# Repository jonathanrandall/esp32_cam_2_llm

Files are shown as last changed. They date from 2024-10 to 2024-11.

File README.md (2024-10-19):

# esp32_cam_2_llm
connect an esp32 cam to llm and back again

The project connects an esp32 cam to an LLM, which takes as input the prompt "describe this picture?" together with the image, and then returns a description of the image. The returned description is then transformed into speech. The LLM is running locally on my machine. I'm using the [ollama library](https://ollama.com/) with LLAVA model. The __LLAVA open source model__ is good for doing image analysis. I'm using an MSI laptop with an NVIDIA 4070 GPU, which has 8GB of vram. The llava model can be installed directoy with ollama. 

Thanks to pcbway for the pcbs. https://www.pcbway.com

### explanatory video:

https://youtu.be/hMA0HNYTjm0

### repository files:

* __llm_2_esp32_cam.py__: this file is running on my local maching.
* __esp32_2_llm__: this contains the test internet radio file from the audio [esp32-i2s library](https://github.com/schreibfaul1/ESP32-audioI2S). Try to get this working first to troubleshoot any i2s difficulties.
* __esp32_2_llmv4__: this contains the code running on the eps32 cam that communicates with the llm.
* __fritzing__: fritzing file and gerbers for pcb.

### connections I used
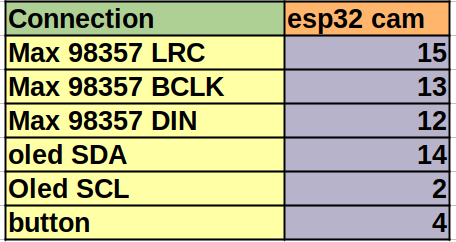
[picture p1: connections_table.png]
connection list


### equipment list

* __esp32 cam__: I'm using the AI thinker.
* __MAX 98357__: Audio amplifier.
* __speakers__: 8 ohm or 4 ohm speakers. It's worth getting good ones. Cheaper ones are at aliexpress (https://www.aliexpress.com/item/1005006056014552.html). More expensive ones are at Amazon (https://www.amazon.com.au/dp/B01LN8ONG4).
* __FTDI adapter__: Need this to flash the esp32 cam if you're using the AI thinker.
* __pcb or breadboard__: I used both. I built on the breadboard first and then put everything on a pcb.
* __oled__: I used a 128 x 64 oled.
* __18650 battery__
* __18650 WEMOS battery shield__: see https://www.amazon.com.au/Be-Your-Mind-Expansion-Compatible/dp/B0CPDD985S for example.
* __push button__
* __rocker switch__
* __jumper cables__

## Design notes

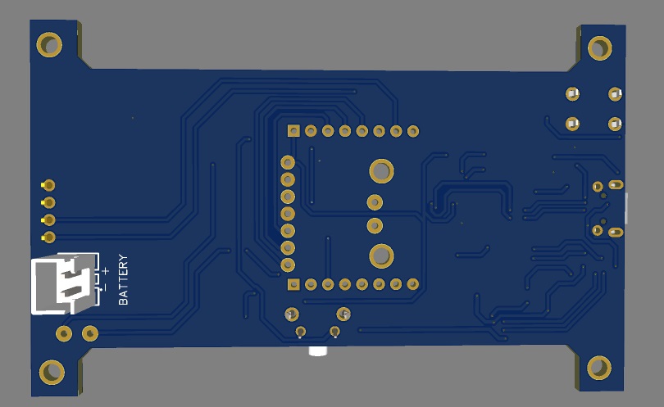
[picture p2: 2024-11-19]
fritzing/llmB.jpg

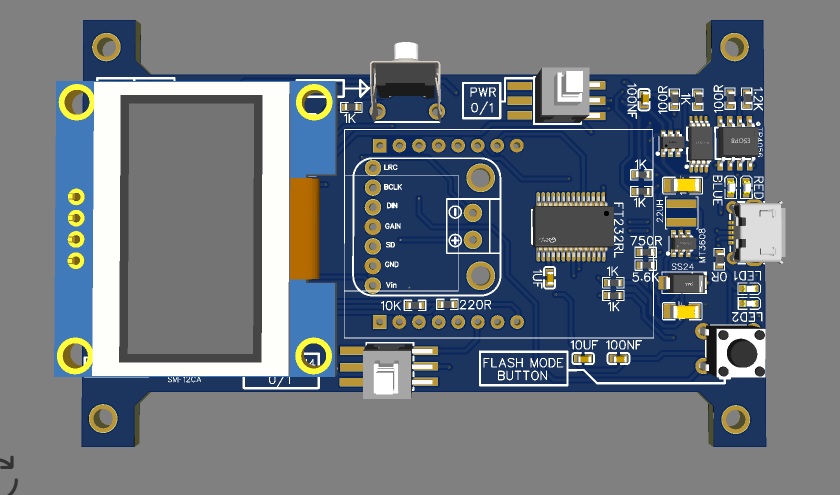
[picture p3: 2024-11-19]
fritzing/llmA.jpg

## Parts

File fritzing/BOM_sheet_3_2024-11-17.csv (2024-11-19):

ID | Name | Designator | Footprint | Quantity | Manufacturer Part | Manufacturer | Supplier | Supplier Part | Price | JLCPCB Part Class | Value
1 | CONN-TH_2P-P2.50_HX254 | U153 | CONN-TH_2P-P2.50_HX254 | 1 | HX2.54_2 | null | LCSC | C9900001962 |  | Extended Part
2 | SOD-123_L2.8-W1.8-LS3.7-BI | D1 | SOD-123_L2.8-W1.8-LS3.7-BI | 1 | SMF12CA | SUNMATE(森美特) | LCSC | C399256 | 0.029 | Extended Part
3 | ESP32-CAM | 1 | ESP32-CAM | 1
4 | SW-SMD_G-SWITCH_PS-5850SVX-3PL | U148,U8 | SW-SMD_G-SWITCH_PS-5850SVX-3PL | 2 | PS-5850SVB-3PL | G-Switch(品赞) | LCSC | C5159077 | 0.152 | Extended Part
5 | R0603 | 1K,1K,1K,1K,1K,1K | R0603 | 6 | RC0603JR-071KL | YAGEO(国巨) | LCSC | C14676 | 0.001 | Extended Part | 1kΩ
6 | KEY-TH_E-SWITCH_TL6110BF500QP | U7 | KEY-TH_E-SWITCH_TL6110BF500QP | 1 | TL6110BF500QP | E-Switch | LCSC | C4364940 | 0.706
7 | R0603 | 100R,100R | R0603 | 2 | AC0603FR-7W100RL | YAGEO(国巨) | LCSC | C6457824 | 0.004 | Extended Part | 100Ω
8 | C0603 | 100NF,100NF | C0603 | 2 | 0603B104K250CT | Walsin(华新科) | LCSC | C83054 | 0.003 | Extended Part | 100nF
9 | LED0603-RD | BLUE,RED,LED1,LED2 | LED0603-RD | 4 | YLED0603B | YONGYUTAI(永裕泰) | LCSC | C19171394 | 0.005 | Extended Part
10 | SSOP-28_L10.2-W5.3-P0.65-LS7.8-BL | U2 | SSOP-28_L10.2-W5.3-P0.65-LS7.8-BL | 1 | FT232RL-REEL | FTDI(飞特帝亚) | LCSC | C8690 | 4.152 | Extended Part
11 | C0603 | 1UF | C0603 | 1 | CC0603KRX5R8BB105 | YAGEO(国巨) | LCSC | C14664 | 0.005 | Extended Part | 1uF
12 | C0603 | 10UF | C0603 | 1 | HGC0603R5106M250NTHJ | Chinocera(华瓷) | LCSC | C7472961 | 0.015 | Extended Part | 10uF
13 | R0603 | 0R | R0603 | 1 | CR-03FL7----0R | Viking(光颉) | LCSC | C304185 | 0.002 | Extended Part | 0Ω
14 | R0603 | 1.2K | R0603 | 1 | RMC06031.2K1%N | Tyohm(幸亚电阻) | LCSC | C325597 | 0.003 | Extended Part | 1.2kΩ
15 | R0603 | 750R | R0603 | 1 | AECR0603F750RK9 | RESI(开步睿思) | LCSC | C328375 | 0.001 | Extended Part | 750Ω
16 | R0603 | 5.6K | R0603 | 1 | RMC06035.6K5%N | Tyohm(幸亚电阻) | LCSC | C325756 | 0.002 | Extended Part | 5.6kΩ
17 | R0603 | 10K | R0603 | 1 | AC0603FR-0710KL | YAGEO(国巨) | LCSC | C116677 | 0.002 | Extended Part | 10kΩ
18 | R0603 | 220R | R0603 | 1 | RC0603JR-07220RL | YAGEO(国巨) | LCSC | C114683 | 0.001 | Extended Part | 220Ω
19 | KEY-TH_4P-L6.0-W6.0-P4.50 | U3 | KEY-TH_4P-L6.0-W6.0-P4.50 | 1 | button6*6*8.5 | ReliaPro | LCSC | C59980 | 0.016 | Extended Part
20 | IND-SMD_L4.0-W4.0-A | L4 | IND-SMD_L4.0-W4.0-A | 1 | XFL4020-102ME | null | LCSC | C9900014800 |  | Extended Part
21 | C1206 | C87,C86 | C1206 | 2 | GRM31CR60J476ME19L | muRata(村田) | LCSC | C77087 | 0.083 | Extended Part | 47uF
22 | SOT-23-6_L2.9-W1.6-P0.95-LS2.8-BL | U147 | SOT-23-6_L2.9-W1.6-P0.95-LS2.8-BL | 1 | MT3608 | 西安航天民芯 | LCSC | C84817 | 0.062 | Extended Part
23 | SMA_L4.4-W2.6-LS5.0-RD | D20 | SMA_L4.4-W2.6-LS5.0-RD | 1 | SM340A | LRC(乐山无线电) | LCSC | C383313 | 0.032 | Extended Part
24 | 0.96OLED_4P | OLED1 | 0.96OLED_4P | 1 | 0.96OLED_4P_MODULE_JX | null | LCSC | C9900004566 |  | Extended Part
25 | MAX98357A | U6 | MAX98357A | 1 |  |  | ebay
26 | ESOP-8_L4.9-W3.9-P1.27-LS6.0-BL-EP | U103 | ESOP-8_L4.9-W3.9-P1.27-LS6.0-BL-EP | 1 | TP4056 | null | LCSC | C9900002169 |  | Extended Part
27 | TSSOP-8_L4.4-W3.0-P0.65-LS6.4-BL | U102 | TSSOP-8_L4.4-W3.0-P0.65-LS6.4-BL | 1 | 8205LA | FM(富满) | LCSC | C7420387 | 0.031
28 | SOT-23-6_L2.9-W1.6-P0.95-LS2.9-BL | U101 | SOT-23-6_L2.9-W1.6-P0.95-LS2.9-BL | 1 | DW01-G | FORTUNE(富晶) | LCSC | C3020704
29 | MICRO-USB_MICRO-USB-30 | USB2 | MICRO-USB_MICRO-USB-30 | 1 | 920-E52A2021S10101 | 精拓金 | LCSC | C40946 | 0.069 | Extended Part

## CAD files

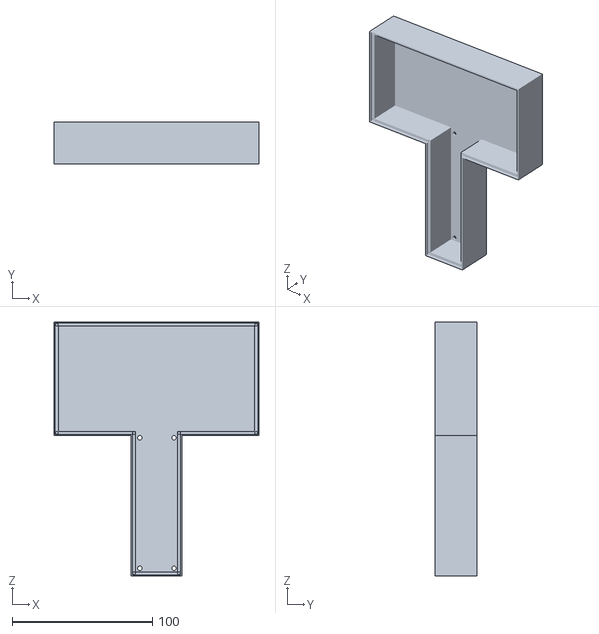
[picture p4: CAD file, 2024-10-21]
3d_prints/box-Body.stl
146.0 x 30.0 x 181.0

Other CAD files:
3d_prints/project_box_esp32_llm.FCStd

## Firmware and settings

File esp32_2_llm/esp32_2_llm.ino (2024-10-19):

/*
  Simple Internet Radio Demo
  esp32-i2s-simple-radio.ino
  Simple ESP32 I2S radio
  Uses MAX98357 I2S Amplifier Module
  Uses ESP32-audioI2S Library - https://github.com/schreibfaul1/ESP32-audioI2S

  DroneBot Workshop 2022
  https://dronebotworkshop.com
*/

// Include required libraries
#include "Arduino.h"
#include "WiFi.h"
#include "Audio.h"

#define RTC_CNTL_BROWN_OUT_REG          (DR_REG_RTCCNTL_BASE + 0xd4)

// Define I2S connections
#define I2S_DOUT  12
#define I2S_BCLK  13
#define I2S_LRC   15

// Create audio object
Audio audio;

// Wifi Credentials
String ssid =    "";
String password = "";

void setup() {
  WRITE_PERI_REG(RTC_CNTL_BROWN_OUT_REG, 0); //disable brownout detector

  // Start Serial Monitor
  Serial.begin(115200);

  // Setup WiFi in Station mode
  WiFi.disconnect();
  WiFi.mode(WIFI_STA);
  WiFi.begin(ssid.c_str(), password.c_str());

  while (WiFi.status() != WL_CONNECTED) {
    delay(500);
    Serial.print(".");
  }

  // WiFi Connected, print IP to serial monitor
  Serial.println("");
  Serial.println("WiFi connected");
  Serial.println("IP address: ");
  Serial.println(WiFi.localIP());
  Serial.println("");

  // Connect MAX98357 I2S Amplifier Module
  audio.setPinout(I2S_BCLK, I2S_LRC, I2S_DOUT);

  // Set thevolume (0-100)
  audio.setVolume(10);

  // Connect to an Internet radio station (select one as desired)
  audio.connecttohost("http://vis.media-ice.musicradio.com/CapitalMP3");
  //audio.connecttohost("mediaserv30.live-nect MAX98357 I2S Amplifier Module
  //audio.connecttohost("www.surfmusic.de/m3u/100-5-das-hitradio,4529.m3u");
  //audio.connecttohost("stream.1a-webradio.de/deutsch/mp3-128/vtuner-1a");
  //audio.connecttohost("www.antenne.de/webradio/antenne.m3u");
  // audio.connecttohost("0n-80s.radionetz.de:8000/0n-70s.mp3");

}

void loop()

{
  // Run audio player
  audio.loop();

}

// Audio status functions

void audio_info(const char *info) {
  Serial.print("info        "); Serial.println(info);
}
void audio_id3data(const char *info) { //id3 metadata
  Serial.print("id3data     "); Serial.println(info);
}
void audio_eof_mp3(const char *info) { //end of file
  Serial.print("eof_mp3     "); Serial.println(info);
}
void audio_showstation(const char *info) {
  Serial.print("station     "); Serial.println(info);
}
void audio_showstreaminfo(const char *info) {
  Serial.print("streaminfo  "); Serial.println(info);
}
void audio_showstreamtitle(const char *info) {
  Serial.print("streamtitle "); Serial.println(info);
}
void audio_bitrate(const char *info) {
  Serial.print("bitrate     "); Serial.println(info);
}
void audio_commercial(const char *info) { //duration in sec
  Serial.print("commercial  "); Serial.println(info);
}
void audio_icyurl(const char *info) { //homepage
  Serial.print("icyurl      "); Serial.println(info);
}
void audio_lasthost(const char *info) { //stream URL played
  Serial.print("lasthost    "); Serial.println(info);
}
void audio_eof_speech(const char *info) {
  Serial.print("eof_speech  "); Serial.println(info);
}

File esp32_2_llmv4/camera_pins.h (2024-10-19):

#ifndef PINS_STUFF_
#define PINS_STUFF_

// Select camera model
// #define CAMERA_MODEL_WROVER_KIT // Has PSRAM
//#define CAMERA_MODEL_ESP_EYE // Has PSRAM
//#define CAMERA_MODEL_M5STACK_PSRAM // Has PSRAM
//#define CAMERA_MODEL_M5STACK_WIDE  // Has PSRAM
#define CAMERA_MODEL_AI_THINKER // Has PSRAM
//#define CAMERA_MODEL_TTGO_T_JOURNAL // No PSRAM
// #define CAMERA_MODEL_XIAO_ESP32S3 // Has PSRAM
#if defined(CAMERA_MODEL_WROVER_KIT)
#define PWDN_GPIO_NUM    -1
#define RESET_GPIO_NUM   -1
#define XCLK_GPIO_NUM    21
#define SIOD_GPIO_NUM    26
#define SIOC_GPIO_NUM    27

#define Y9_GPIO_NUM      35
#define Y8_GPIO_NUM      34
#define Y7_GPIO_NUM      39
#define Y6_GPIO_NUM      36
#define Y5_GPIO_NUM      19
#define Y4_GPIO_NUM      18
#define Y3_GPIO_NUM       5
#define Y2_GPIO_NUM       4
#define VSYNC_GPIO_NUM   25
#define HREF_GPIO_NUM    23
#define PCLK_GPIO_NUM    22

#elif defined(CAMERA_MODEL_ESP_EYE)
#define PWDN_GPIO_NUM    -1
#define RESET_GPIO_NUM   -1
#define XCLK_GPIO_NUM    4
#define SIOD_GPIO_NUM    18
#define SIOC_GPIO_NUM    23

#define Y9_GPIO_NUM      36
#define Y8_GPIO_NUM      37
#define Y7_GPIO_NUM      38
#define Y6_GPIO_NUM      39
#define Y5_GPIO_NUM      35
#define Y4_GPIO_NUM      14
#define Y3_GPIO_NUM      13
#define Y2_GPIO_NUM      34
#define VSYNC_GPIO_NUM   5
#define HREF_GPIO_NUM    27
#define PCLK_GPIO_NUM    25

#define LED_GPIO_NUM     22

#elif defined(CAMERA_MODEL_M5STACK_PSRAM)
#define PWDN_GPIO_NUM     -1
#define RESET_GPIO_NUM    15
#define XCLK_GPIO_NUM     27
#define SIOD_GPIO_NUM     25
#define SIOC_GPIO_NUM     23

#define Y9_GPIO_NUM       19
#define Y8_GPIO_NUM       36
#define Y7_GPIO_NUM       18
#define Y6_GPIO_NUM       39
#define Y5_GPIO_NUM        5
#define Y4_GPIO_NUM       34
#define Y3_GPIO_NUM       35
#define Y2_GPIO_NUM       32
#define VSYNC_GPIO_NUM    22
#define HREF_GPIO_NUM     26
#define PCLK_GPIO_NUM     21

#elif defined(CAMERA_MODEL_M5STACK_V2_PSRAM)
#define PWDN_GPIO_NUM     -1
#define RESET_GPIO_NUM    15
#define XCLK_GPIO_NUM     27
#define SIOD_GPIO_NUM     22
#define SIOC_GPIO_NUM     23

#define Y9_GPIO_NUM       19
#define Y8_GPIO_NUM       36
#define Y7_GPIO_NUM       18
#define Y6_GPIO_NUM       39
#define Y5_GPIO_NUM        5
#define Y4_GPIO_NUM       34
#define Y3_GPIO_NUM       35
#define Y2_GPIO_NUM       32
#define VSYNC_GPIO_NUM    25
#define HREF_GPIO_NUM     26
#define PCLK_GPIO_NUM     21

#elif defined(CAMERA_MODEL_M5STACK_WIDE)
#define PWDN_GPIO_NUM     -1
#define RESET_GPIO_NUM    15
#define XCLK_GPIO_NUM     27
#define SIOD_GPIO_NUM     22
#define SIOC_GPIO_NUM     23

#define Y9_GPIO_NUM       19
#define Y8_GPIO_NUM       36
#define Y7_GPIO_NUM       18
#define Y6_GPIO_NUM       39
#define Y5_GPIO_NUM        5
#define Y4_GPIO_NUM       34
#define Y3_GPIO_NUM       35
#define Y2_GPIO_NUM       32
#define VSYNC_GPIO_NUM    25
#define HREF_GPIO_NUM     26
#define PCLK_GPIO_NUM     21

#define LED_GPIO_NUM       2

#elif defined(CAMERA_MODEL_M5STACK_ESP32CAM)
#define PWDN_GPIO_NUM     -1
#define RESET_GPIO_NUM    15
#define XCLK_GPIO_NUM     27
#define SIOD_GPIO_NUM     25
#define SIOC_GPIO_NUM     23

#define Y9_GPIO_NUM       19
#define Y8_GPIO_NUM       36
#define Y7_GPIO_NUM       18
#define Y6_GPIO_NUM       39
#define Y5_GPIO_NUM        5
#define Y4_GPIO_NUM       34
#define Y3_GPIO_NUM       35
#define Y2_GPIO_NUM       17
#define VSYNC_GPIO_NUM    22
#define HREF_GPIO_NUM     26
#define PCLK_GPIO_NUM     21

#elif defined(CAMERA_MODEL_M5STACK_UNITCAM)
#define PWDN_GPIO_NUM     -1
#define RESET_GPIO_NUM    15
#define XCLK_GPIO_NUM     27
#define SIOD_GPIO_NUM     25
#define SIOC_GPIO_NUM     23

#define Y9_GPIO_NUM       19
#define Y8_GPIO_NUM       36
#define Y7_GPIO_NUM       18
#define Y6_GPIO_NUM       39
#define Y5_GPIO_NUM        5
#define Y4_GPIO_NUM       34
#define Y3_GPIO_NUM       35
#define Y2_GPIO_NUM       32
#define VSYNC_GPIO_NUM    22
#define HREF_GPIO_NUM     26
#define PCLK_GPIO_NUM     21

#elif defined(CAMERA_MODEL_AI_THINKER)
#define PWDN_GPIO_NUM     32
#define RESET_GPIO_NUM    -1
#define XCLK_GPIO_NUM      0
#define SIOD_GPIO_NUM     26
#define SIOC_GPIO_NUM     27

#define Y9_GPIO_NUM       35
#define Y8_GPIO_NUM       34
#define Y7_GPIO_NUM       39
#define Y6_GPIO_NUM       36
#define Y5_GPIO_NUM       21
#define Y4_GPIO_NUM       19
#define Y3_GPIO_NUM       18
#define Y2_GPIO_NUM        5
#define VSYNC_GPIO_NUM    25
#define HREF_GPIO_NUM     23
#define PCLK_GPIO_NUM     22

// #define LED_GPIO_NUM      33

#elif defined(CAMERA_MODEL_TTGO_T_JOURNAL)
#define PWDN_GPIO_NUM      0
#define RESET_GPIO_NUM    15
#define XCLK_GPIO_NUM     27
#define SIOD_GPIO_NUM     25
#define SIOC_GPIO_NUM     23
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

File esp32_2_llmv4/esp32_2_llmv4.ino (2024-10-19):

// Include required libraries
#include "Arduino.h"
#include "WiFi.h"
#include "Audio.h"
#include "wifi_stuff.h"
#include "camera_stuff.h"
#include "audio_stuff.h"
#include "oled_stuff.h"

// #include "camera_stuff.h"

#include "soc/soc.h" // Disable brownout problems
#include "soc/rtc_cntl_reg.h" // Disable brownout problems
// Define I2S connections

// Wifi Credentials

#define button_pin 4


// Audio audio;
bool playAudio = false;  // Flag to control when audio is played
static unsigned long startMillis;

void show_ip(){
  display.clearDisplay();
    display.setTextSize(1);
  display.setTextColor(SSD1306_WHITE);
  display.setCursor(10, 10);
  display.println(WiFi.localIP());
  display.display();
}

void setup() {
  WRITE_PERI_REG(RTC_CNTL_BROWN_OUT_REG, 0); //disable brownout detector
  Serial.begin(115200);
  Semaphore_Controls = xSemaphoreCreateMutex();
  Semaphore_wait = xSemaphoreCreateMutex();
  audioPlayQueue = xQueueCreate(1, sizeof(bool));
  // audio.setPinout(I2S_BCLK, I2S_LRC, I2S_DOUT);
  
  // delay(1000);
  // esp_camera_deinit();
  pinMode(button_pin, INPUT);


  // Connect to Wi-Fi
  init_wifi();
  delay(50);
  Serial.print("starting camera");
  init_camera();
  delay(50);
  startCameraServer();
  Serial.println("starging oled");

  init_oled();
  Serial.println("showing ip");
  show_ip();

  // display.setTextSize(1);
  // display.setTextColor(SSD1306_WHITE);
  // display.setCursor(10, 10);
  // display.println(WiFi.localIP());
  // display.display();

  xTaskCreatePinnedToCore(
       play_audio, /* Function to implement the task */
       "rm",    /* Name of the task */
       1024*10,            /* Stack size in words */
       NULL,            /* Task input parameter */
       2,               /* Priority of the task */
       NULL,     /* Task handle. */
       1);              /* Core where the task should run */

  // delay(3000);
  // capture_camera = false;
  // delay(400);
  // esp_camera_deinit();
  // delay(500);
  // startCameraServer();

   // Connect MAX98357 I2S Amplifier Module
  //  i2s_driver_uninstall(I2S_NUM_0);
  // play_audio();

  // Serial.println("audio finished");
  // // delay(200);
  // while(init_camera()<0){
  //   Serial.println("init camera");
  // }
  // capture_camera = true;
}
bool next_cmd = true;
void loop() {

  
  // audio.loop(); 
  // delay(20);
  // // Simulate doing some task
  // Serial.println("Performing a task...");
  delay(100);  // Simulate task for 5 seconds

  if(digitalRead(button_pin))
  // if (next_cmd)
  {
    xSemaphoreTake(Semaphore_Controls,  portMAX_DELAY);
    Serial.println("button read");
    esp_camera_deinit();
    while(digitalRead(button_pin)){
      //wait for led to turn off
    }
    delay(200);
    request_inference();
    Serial.println("requesting");
    waiting_resp = true;
    // delay(500);
    // digitalWrite(4, LOW);           // Set GPIO 4 to HIGH (turn on LED, for example)
  
    // rtc_gpio_hold_en(GPIO_NUM_4);
    // xSemaphoreTake(Semaphore_Controls,  portMAX_DELAY);
    while (waiting_resp){
      delay(500);
      oled_write("waiting");
    }
    oled_write("received");
    play_audio2();
    xSemaphoreGive(Semaphore_Controls);
    // xSemaphoreGive(Semaphore_wait);
    // xQueueSend(audioPlayQueue, &next_cmd, portMAX_DELAY);
    // delay(10);
    // xSemaphoreTake(Semaphore_wait,  portMAX_DELAY);
    delay(200);
    if(init_camera()<0){
      Serial.println("init camera failed");
      oled_write("init cam failed");
      vTaskDelay( 500 / portTICK_PERIOD_MS);
      ESP.restart();
    }
    show_ip();
    next_cmd = false;
  }

  // // Set the flag to start playing audio after the task is complete
  // if (!playAudio) {
  //   playAudio = true;  // Set the flag to true to trigger audio playback
  //   Serial.println("Task completed, starting audio...");

  //   // Start streaming the audio from the local HTTP server
  //   audio.connecttohost("http://jonny-ubuntu.local:8000/output.wav");
  // }

  // // Check if audio is playing and call audio.loop() to keep it playing
  // if (playAudio) {
  //   audio.loop();  // This ensures the audio continues to play
  // }

  // // Stop the audio after a condition (e.g., after a certain time)
  // if (false && audio.isRunning() && someConditionToStop()) {
  //   Serial.println("Stopping audio...");
  //   audio.stopSong();  // Stop the current song
  //   playAudio = false;  // Reset flag so it doesn't loop the audio
  // }
}

// Define a function that stops the audio after a certain condition (e.g., time)
bool someConditionToStop() {
  // Example condition: stop after a delay or when task finishes
  
  if (millis() - startMillis > 20000) {  // Stop after 15 seconds of playing
    startMillis = millis();
    return true;
  }
  return false;
}
